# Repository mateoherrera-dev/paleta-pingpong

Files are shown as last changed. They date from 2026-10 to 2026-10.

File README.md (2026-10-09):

# Paleta de ping pong inteligente

Un sensor en el mango de la paleta reconoce cada golpe, mide el angulo de la paleta en el impacto y si el jugador frena antes de la pelota, y muestra un consejo en el celular.

- **Plan de trabajo, modulos y tareas por clase:** [`docs/PLAN.md`](docs/PLAN.md)
- **Formatos de datos entre modulos:** [`docs/CONTRATOS.md`](docs/CONTRATOS.md)

## Estructura

| Carpeta | Que va | Modulo |
| --- | --- | --- |
| `firmware/paleta/` | Codigo de la placa (Arduino IDE) | A |
| `herramientas/` | Python: grabar sesiones, graficarlas, procesar la señal | B y D |
| `app/` | App web que se conecta a la paleta por Bluetooth | C |
| `hardware/` | Capsula en OpenSCAD | E |
| `datos/` | Sesiones grabadas. **No se suben a git**: van al Drive del grupo | Todos |
| `docs/` | Plan, contratos, protocolo de grabacion, criterios | Todos |

## Como arrancar

### Firmware (modulo A)

Configuracion de la placa en el Arduino IDE (la camara no se usa):

- Placa: **ESP32S3 Dev Module**
- Flash Size: **16MB**
- PSRAM: **OPI PSRAM**
- Partition Scheme: **16M Flash (3MB APP/9.9MB FATFS)**
- Si se usa el USB nativo para el monitor serie: USB CDC On Boot → **Enabled**

Conexion del MPU-6500 por SPI (con los nombres que trae impresos el modulo):

| Modulo MPU-6500 | Funcion | ESP32-S3 |
| --- | --- | --- |
| VCC | Alimentacion | 3V3 |
| GND | Masa | GND |
| SCL | SCK (reloj) | GPIO 42 |
| SDA | MOSI | GPIO 41 |
| AD0 | MISO | GPIO 14 |
| NCS | CS | GPIO 21 |
| INT | Dato listo (interrupcion) | GPIO 1 |
| FSYNC, EDA, ECL | - | Sin conectar |

Antes de conectar, revisar en el pinout de su placa que esos GPIO esten libres. Si no, cambiar los `PIN_...` al principio de `paleta.ino`. Al arrancar, el monitor serie tiene que mostrar `# MPU-6500 encontrado (WHO_AM_I = 0x70)`.

Abrir `firmware/paleta/paleta.ino`, cargarlo y abrir el monitor serie a **921600 baudios**.

### Herramientas en Python (modulos B y D)

```bash
cd herramientas
pip install -r requirements.txt
python ejemplo.py
python ver.py ../datos/crudos/ejemplo_sintetico.csv
```

Con la placa conectada:

```bash
python grabar.py --listar
python grabar.py --puerto COM5 --jugador mateo --golpe topspin_derecha
```

### App (modulo C)

Desde la carpeta raiz del proyecto:

```bash
python -m http.server 8000
```

Abrir `http://localhost:8000/app/` en Chrome y tocar **Simulador**. Para usarla en el celular con la placa real hace falta https: publicarla con GitHub Pages.

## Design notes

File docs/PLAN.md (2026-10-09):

# Plan de trabajo

**Condiciones:** somos 3 y trabajamos solo los viernes, de 9 a 16 (a veces hasta las 18). Entre semana no hay trabajo de proyecto, salvo tramites cortos: compras e impresion 3D.

**Calendario:** hoy (viernes 2/10) es la clase 0. El MVP tiene que estar terminado el **viernes 13/11**. Despues viene la fase 2, hasta la entrega final.

| Clase | 1 | 2 | 3 | 4 | 5 | 6 |
| --- | --- | --- | --- | --- | --- | --- |
| Viernes | 9/10 | 16/10 | 23/10 | 30/10 | 6/11 | **13/11 · MVP** |

No hay un viernes de colchon al final. El margen sale de dos lados: el horario de 16 a 18 de cada viernes, y el 13/11, que esta pensado para cerrar y arreglar, no para agregar cosas.

**Objetivo del MVP:** alguien pega un golpe y el celular muestra **que golpe fue, con que angulo pego la paleta y la velocidad de swing estimada ($v = \omega \cdot r$)**, junto con un consejo tecnico.

**Definicion de terminado del MVP:**
- Reconoce 4 golpes (topspin y empuje, de derecha y de reves) con **80 % de aciertos o mas**, medido con gente que no se uso para entrenar.
- Inferencia y metricas locales en el ESP32-S3 (TinyML / Edge Impulse) enviadas por paquete BLE liviano (< 20 bytes) al impactar.
- Muestra en el celular el angulo en el impacto y si el pico de aceleracion angular ocurrio antes de la bola.
- Funciona sin cables a la compu: alimentado por powerbank en el bolsillo via USB-C.

YOLO-pose y el analisis de postura van en la **fase 2**, despues del 13/11.

---

## 1. Equipo y modulos

Los formatos de datos entre modulos estan fijados en [`CONTRATOS.md`](CONTRATOS.md).

| Persona | Modulos | Que hace | Suplente |
| --- | --- | --- | --- |
| **P1 · Hardware** | Firmware base | Sensor MPU-6500 por SPI a 1000 Hz (interrupciones/DMA), deteccion de impactos (trigger), emision de struct BLE (NimBLE) | P2 |
| **P2 · Datos** | Datos, Modelo + 3D | Grabacion (UART), dataset, entrenamiento Edge Impulse, modulo wrapper C++ (`ml_inference.h`), diseño e impresion de capsula (Fusion 360) | P3 |
| **P3 · Tecnica** | App + UI + BLE | Contrato de payload BLE, App web (Web Bluetooth API), calculo cinematico ($v = \omega \cdot L$), angulos (Madgwick), criterios y consejos | P1 |

### Reglas

- **El suplente sabe como funciona el modulo** que cubre, por si el dueño falta un viernes.
- **Los tres graban datos.** La grabacion es una actividad de grupo, no del modulo de datos solo.
- **Integrar todos los viernes.** Cada viernes a la tarde se prueba de punta a punta lo que haya, aunque sea con datos simulados.
- **Los contratos no se cambian solos:** se discute entre los tres y se actualiza `CONTRATOS.md`.
- **Git:** una rama corta por tarea y PR a `main` (que esta protegida), merge cuando compile y ande. Todo pusheado antes de irse cada viernes. Detalle en [`AGENTS.md`](../AGENTS.md).

---

## 2. Como es un viernes

| Horario | Que se hace |
| --- | --- |
| 9:00 – 9:20 | Arranque: que quedo del viernes pasado, que hito tenemos que mostrar hoy |
| 9:20 – 12:30 | **Trabajo por modulos**, cada uno en lo suyo |
| 12:30 – 13:30 | Almuerzo |
| 13:30 – 15:00 | **Bloque de grupo:** grabacion, pruebas con gente o integracion |
| 15:00 – 15:45 | Prueba de punta a punta y control del hito del dia |
| 15:45 – 16:00 | Cierre: commit, tablero, compras y tareas del proximo viernes |
| 16:00 – 18:00 | **Colchon:** solo para lo atrasado, no para cosas nuevas |

---

## 3. Clase 0: hoy

### Organizacion (los tres, primera hora)

- [ ] Confirmar roles: P1, P2 y P3.
- [ ] **Comprar por internet** para recibir antes del 9/10: **2 modulos MPU-6500** (uno de repuesto), cables dupont hembra-hembra, cable USB-C flexible largo (2–3 m) cinta de pintor, cinta bifaz 3M VHB y cinta aisladora. Alternativa de respaldo: 2 discos piezoelectricos chicos por si el trigger por acelerometro mete ruido.
- [ ] Crear el repo en GitHub, subir estructura base y dar permisos al equipo.
- [ ] Crear la carpeta de Drive para los CSV crudos.
- [ ] **Confirmar mesa de ping pong disponible los viernes a la tarde**, red portatil, 2 paletas y minimo 20 pelotas para tiros en rafaga.
- [ ] Averiguar proveedor de impresion 3D y tiempos de entrega (impresion entre Clase 3 y 4).
- [ ] Contactar al jugador de referencia para coordinar su asistencia el viernes 30/10 (Clase 4).

### Codigo y Banco (sin sensor fisico aun)

| Quien | Tarea | Listo cuando… |
| --- | --- | --- |
| **P2** | Escribir modulo wrapper C++ (`ml_inference.h/cpp`) integrando el modelo Edge Impulse sintetico (`firmware/modelo_dummy_sintetico.zip`) | Modulo encapsulado listo con funcion `predecir_golpe()` |
| **P2** | Script receptor en Python por puerto serie (lectura a 921600 baudios) y visualizador `ver.py` | Recibe paquetes simulados a 1000 Hz sin dropping de buffers |
| **P2** | Escribir protocolo de captura (`docs/PROTOCOLO.md`): orden de tiros, estructura y metadatos de CSV | Protocolo cerrado |
| **P3** | App web base (Web Bluetooth API) desplegada en GitHub Pages | Conecta y parsea el string de prueba del contrato |
| **P3** | Definir rangos biomecanicos preliminares (angulos de impacto y velocidad tangencial) | Tabla base en `docs/` |

---

## 4. Fase 1: MVP, viernes por viernes

### Clase 1 · Viernes 9/10 · Señal real y adquisicion a 1000 Hz (Alimentacion: Cable USB-C a PC)
**Materiales a llevar:** Placa ESP32-S3, MPU-6500, cable USB-C largo (2-3 m), paleta, cinta de pintor, cinta bifaz 3M VHB, cinta aisladora / edge tape, pelotas de ping pong.

| P1 | P2 | P3 |
| --- | --- | --- |
| Configurar IDE para ESP32-S3 y linkear `ml_inference.h` (prueba dummy). Mapear pines, conectar MPU-6500 por SPI $\ge 1\text{ MHz}$, y configurar muestreo a 1000 Hz por interrupcion | Modelar capsula de la placa en Fusion 360 midiendo componentes. Validar aislacion del impacto real vs swings al aire | Algoritmo de orientacion (Madgwick/Mahony) en Python procesando las rafagas. Definir contrato de payload BLE (struct C) |

**Tarde:** 
1. **Montaje provisorio (13:30):** Pegar la plaqueta pelada del MPU-6500 a la madera usando cinta de pintor + VHB, y encintar los cables al canto (protocolo 7.3) para evitar ruido mecanico. Al terminar el dia se despega todo.
2. **Grabacion:** 30-40 min de capturas con cable USB largo (swings al aire vs. golpes reales contra pelota).
**Hito:** Señal limpia a 1000 Hz en PC y trigger de impacto validado sin falsos positivos.
*⚠️ Salvavidas (Plan B):* Si a las 11:30 AM P1 no logra estabilizar las interrupciones de hardware, abortar y usar un bucle de *polling* bruto (`delayMicroseconds`) para garantizar la grabacion de la tarde.

### Clase 2 · Viernes 16/10 · Grabacion masiva del Dataset (Alimentacion: Cable USB-C a PC)
**Materiales a llevar:** Setup fisico de Clase 1, MPU-6500 de repuesto, cinta plana de 7 vias, cinta Kapton, termocontraible fino, minimo 20 pelotas de ping pong y red portatil.

| P1 | P2 | P3 |
| --- | --- | --- |
| Implementar buffer circular en ESP32-S3 (congelar ventana de 200 ms alrededor del impacto) y testear BLE en dummy | Script de segmentacion automatica de impactos y formateo directo para Edge Impulse | Pruebas de estimacion de velocidad tangencial ($v = \omega_{\text{swing}} \cdot L$) y visualizacion en tiempo real |

**Montaje definitivo del sensor (Clase 2):** la capsula impresa no llega para esta clase, pero el sensor ya queda pegado en su lugar final. La capsula es solo una tapa que no toca el sensor y se agrega en la Clase 4 sin moverlo, asi que el dataset de la tarde se graba con el montaje que va a tener la paleta terminada.

1. **Preparacion del sensor de repuesto (Hardware limpio)**
   - No soldar la tira de pines (headers) recta: Dejar los orificios del PCB libres de conectores macho.
   - Soldar cable plano (ribbon cable) directamente a los pads:
     - Cortar un tramo de cinta plana de 7 vias (longitud aprox. 12 a 15 cm hasta la base del mango).
     - Pelar y estañar las puntas apenas 1 mm.
     - Soldar cada hilo directamente en los orificios de la interfaz SPI: VCC, GND, SCL/SCLK, SDA/SDI, AD0/SDO, NCS e INT.
     - Doblar los cables en un angulo plano de 90° inmediatamente al salir del estaño hacia el mango.
   - Aislacion y perfil bajo: Colocar cinta Kapton sobre las soldaduras para evitar contactos. Espesor total: < 3 mm.
   - Recalibrar el offset del acelerometro con `herramientas/calibrar.py` (es otro modulo) y actualizar `OFFSET_A*_G` en `paleta.ino`.

2. **Fijacion en la madera**
   - Marcar en el cuello el contorno de la capsula (medidas en la seccion 7.1), para que el sensor quede donde despues lo va a tapar.
   - Pegar el MPU con cinta de pintor + VHB (seccion 7.3), rigido contra la madera y **paralelo a la cara de la paleta**, no apoyado sobre el chaflan. Si queda inclinado, los ejes dejan de coincidir con `CONTRATOS.md` y el angulo de la cara sale corrido.
   - Llevar la cinta plana por el canto del mango y cubrirla con edge tape (seccion 7.3).

3. **Conexion hacia el mango**
   - En el extremo del cable plano en el mango, soldar terminales dupont hembra (sirven los de cables dupont cortados, con termocontraible) para conectar a la ESP32-S3, respetando los pines SPI ya probados: SCL→42, SDA→41, AD0→14, NCS→21, INT→1.
   - Comprobar continuidad con multimetro antes de encender para descartar cortos entre lineas SPI adyacentes.

4. **Verificar ejes y angulo (antes de grabar)**
   - Paleta acostada con la goma roja arriba y el mango fuera del borde de la mesa (asi la cara queda horizontal): tiene que dar `az` ≈ +1 g y `ax`, `ay` ≈ 0 g.
     - Si `az` da −1 g, el modulo quedo mirando para el lado negro: invertir los ejes en `alinearEjes()`.
     - Si `ax` o `ay` se alejan de 0 (0.05 g ≈ 3°), el sensor quedo inclinado: volver a pegarlo derecho o corregir esa inclinacion en `alinearEjes()`.
   - Paleta vertical con el mango abajo: tiene que dar `ax` ≈ +1 g.

**Tarde: Grabacion masiva** con el sensor ya en su lugar definitivo. Los tres: 50 golpes por tipo (Topspin Der/Rev, Empuje Der/Rev) $\approx$ 600 tiros.
**Hito:** Sensor de repuesto montado en su lugar definitivo y Dataset v1 subido a Drive y segmentado para entrenamiento.
*⚠️ Criterio de Trigger (Plan B):* Evaluar si el acelerometro detecta limpiamente el impacto sin falsos positivos. Si anda bien, se descarta el piezoelectrico. Si mete ruido, el piezoelectrico entra al diseño 3D y hardware de inmediato.

### Clase 3 · Viernes 23/10 · Despliegue TinyML y Pase a Inalambrico (Alimentacion: Powerbank en bolsillo)
**Materiales a llevar:** Paleta ensamblada provisional, Powerbank de bolsillo, cable USB-C estandar (bolsillo a paleta), celular de prueba para P3.

| P1 | P2 | P3 |
| --- | --- | --- |
| Pasar a alimentacion por Powerbank (verificar que no corte) y emitir struct de prediccion por NimBLE al detectar impacto | Entrenar modelo en Edge Impulse, optimizar cuantizacion INT8, exportar C++ y actualizar `ml_inference.h` | Conectar app web con el BLE real: parsear struct (payload C cerrado) y actualizar UI al impacto |

**Tarde:** Capturar a 3–5 compañeros de la facultad con la paleta inalambrica para validar precision fuera del dataset de entrenamiento.
**Hito:** Precision medida en hardware real.
- $\ge 80\%$: se avanza a integracion final.
- $60\% - 80\%$: reentrenamiento con golpes ambiguos.
- $< 60\%$: reducir alcance a 3 golpes.

**Durante la semana:** P2 envia la capsula y el capuchon a imprimir en 3D (medidas y parametros de impresion en la seccion 7.1).

### Clase 4 · Viernes 30/10 · Integracion Total y Ensamble Definitivo
**Materiales a llevar:** Piezas impresas en 3D (Capsula y Capuchon traidas por P2), adhesivo removible / masilla, herramientas menores para ensamble final.

| P1 | P2 | P3 |
| --- | --- | --- |
| Calce en seco de la capsula sobre el sensor ya pegado (la cuña apoya plana en el chaflan y la cinta plana pasa holgada), pegar su perimetro con adhesivo removible / masilla sin tocar el sensor, montar la ESP32-S3 en el capuchon y verificar alivio de tension USB | Cargar modelo exportado de Edge Impulse en firmware y verificar estabilidad SPI a 1000 Hz | Enlazar Web App por BLE (struct 14 bytes) y validar refresco de UI con golpes en vivo |

**Tarde (los tres):** Prueba de humo de punta a punta con la paleta ensamblada. 20 golpes de cada tipo entre los integrantes del grupo para chequear autonomia y robustez mecanica.  
**Hito:** Paleta armada en su carcasa definitiva, transmitiendo metricas al celular sin cables a la PC.

---

### Clase 5 · Viernes 6/11 · Validacion Ciega y Ajuste Heuristico
**Materiales a llevar:** Hardware 100% ensamblado y funcional, red y pelotas para las pruebas ciegas.

| P1 | P2 | P3 |
| --- | --- | --- |
| Calibrar umbrales de trigger de impacto para eliminar falsos positivos por roces | Ajustar umbral de confianza en inferencia (descartar tiros ambiguos a clase 4) | Pulir reglas heuristicas de consejos segun cinematica teorica (angulos y pico de giro) |

**Tarde:** Sesion de pruebas de usabilidad y acierto ciego con 3 a 5 compañeros ajenos a la carrera para medir la generalizacion del modelo.  
**Congelamiento de codigo al finalizar la jornada.**  
**Hito:** Precision $\ge 80\%$ validada en personas externas al entrenamiento y codigo 100% congelado.

### Clase 6 · Viernes 13/11 · MVP Terminado
**Materiales a llevar:** MVP completo, Powerbank cargado al 100%, camara o celular extra con buen almacenamiento y tripode para filmar la demo.

- **Mañana:** Calibraciones menores y pruebas de estres de bateria/enlace BLE.
- **Tarde:** Medicion de metricas finales (latencia, acierto, bateria), ensayo general y **filmacion de la demo de respaldo**.

**Hito: MVP 100 % completado.**

---

### 4.7 Calculo de Angulo y Filtro de Orientacion (Parte del MVP)

**¿Por que esta en el MVP?**
En `CONTRATOS.md`, el struct binario de 14 bytes (`BlePayload`) que P1 le manda por Bluetooth a P3 incluye explicitamente el campo:
```cpp
int16_t ang_deg; // 2 bytes: Angulo de la cara (- cerrada, + abierta)
```
Si no calculan la orientacion de la paleta, ese campo viaja en 0 o con basura, y la Web App de P3 no puede mostrar si el jugador impacto con la paleta abierta o cerrada.

#### 1. Donde SI se necesita un filtro (Calculo del angulo de la cara)
Para completar el campo `ang_deg` y saber si la paleta entro abierta o cerrada, necesitas conocer la orientacion espacial de la madera respecto a la gravedad:
- **El problema fisico:** En medio de un swing de tenis de mesa no podes calcular el angulo simplemente con $\arctan(a_z / a_x)$, porque las aceleraciones centripeta y tangencial superan por mucho a la gravedad ($1\text{ g}$) y falsean el vector vertical.
- **La solucion:** Un algoritmo de orientacion espacial (*attitude estimation*) que integre el giroscopio y use el acelerometro para corregir la deriva (*drift*) lentamente.

#### 2. Como resolverlo sin volverse locos en el MVP
No tienen que programar las ecuaciones de Madgwick desde cero en C++. Hay dos caminos directos:

**Opcion A: La via estandar (Libreria probada en Arduino/ESP-IDF)**
Usar la libreria `MadgwickAHRS` (disponible en el gestor de librerias de Arduino). Son apenas dos llamadas:
```cpp
Madgwick filter;
filter.begin(100); // Se actualiza a 100 Hz, no a 1000 Hz

// En el loop:
filter.updateIMU(gx, gy, gz, ax, ay, az);
float pitch = filter.getPitch(); // o el angulo sobre el eje normal
```

**Opcion B: El "atajo" heuristico de MVP (Filtro complementario de 3 lineas)**
Si Madgwick les da problemas de ajuste de ganancia ($\beta$) durante la Clase 1 o 2:
- Antes del swing (cuando la paleta esta casi quieta), calculan el angulo base con el acelerometro: $\theta_{\text{acc}} = \arctan2(a_z, a_x) \cdot \frac{180}{\pi}$.
- Durante los ~150 ms del golpe rapido, integran puramente el giroscopio: $\Delta\theta = \int g_y \, dt$.
- Angulo al impacto = $\theta_{\text{base}} + \Delta\theta$.

#### 3. Implementacion practica: No calcular a 1000 Hz
No es necesario correr el filtro Madgwick a 1000 Hz durante toda la sesion:
- **Fase de preparacion ($t < -150\text{ ms}$):** El jugador prepara el tiro. Ahi el movimiento es suave. Correr Madgwick o un filtro complementario liviano a 100 o 200 Hz mantiene orientado el cuaternion del sistema.
- **Fase de swing rapido / impacto:** Congelas la correccion del acelerometro (pones $\beta = 0$ para que el choque de la pelota no incline la estimacion) e integras puramente la rotacion del giroscopio durante los 50 ms previos al impacto.

**Conclusion de Fase 1 (MVP actual):** Inferencia de los 4 golpes en el ESP32 + calculo del angulo `ang_deg` e impacto por IMU + envio por BLE al celular.

## 5. Fase 2: Video de Entrega y Tracking de Postura (Post 13/11)

- **Grabacion final:** Una sola toma lateral a 3 metros (altura de cadera), 60 fps, con iluminacion uniforme.
- **Superposicion sincronica:** Procesamiento en Python con YOLOv8-pose / YOLO11-pose para extraer esqueleto (17 keypoints), sincronizado con el impacto del sensor via audio del golpe.
- **Comparacion biomecanica:** Contrastar flexion de rodillas y codo del usuario vs. clips de entrenadores de referencia.

---

### 5.1 Modo Tutorial: Entrenador Biomecanico Interactivo (Feature Practica)

Para que el proyecto tenga rigor tecnico y no hagan promesas falsas ante los profesores, hay que tener claro el alcance del sensor.

#### 1. El limite fisico: que puede y que NO puede decir la app
**Lo que el sensor SI sabe (en la paleta):**
- Angulo de la cara en el momento exacto del impacto (`ang_deg`).
- Velocidad tangencial estimada del golpe (`vel_kmh`).
- Cuando acelero la muñeca respecto al impacto (`pico_ms`).
- Si el movimiento fue de cepillado (*brushing*) o de empuje plano/bloqueo (segun los ratios $\omega / a_z$).

**Lo que el sensor NO sabe (y no deben inventar):**
- Posicion de los pies, cadera o codo (eso requeriria camara o sensores en el cuerpo).

**Regla de oro de los feedbacks:**
- La app **nunca** debe decir: *"Abri mas el codo"* o *"Flexiona las rodillas"*.
- La app **si** debe decir: *"Entraste con la cara 15° demasiado abierta"* o *"Aceleraste despues del impacto; el latigo de muñeca tiene que ser antes"*.

#### 2. Como se estructura el "Modo Tutorial"
En la web app de P3, en vez de limitarse a mostrar una tabla de metricas crudas, se armara una pestaña "Academia / Tutoriales" con objetivos por niveles.

**Modulo: "Aprender Topspin de Derecha (Comba)"**
El usuario entra a una pantalla con 3 pasos guiados:

- **Paso 1: Angulo de ataque (Cerrar la cara)**
  - **Objetivo:** Lograr 5 golpes seguidos con la cara cerrada entre $-15^\circ$ y $-35^\circ$.
  - **Feedback visual:** La app muestra un grafico o indicador de aguja.
  - **Regla:** Si `ang_deg > -5°`, disparar audio/texto: *"Paleta muy vertical. Vas a tirar la pelota afuera; cerra la muñeca hacia la mesa"*.

- **Paso 2: El 'Brushing' (Velocidad de roce vs. Choque)**
  - **Objetivo:** Superar los $15\text{ km/h}$ o cierto umbral de aceleracion angular ($\omega_y > 800^\circ/\text{s}$) asegurando que el tipo de golpe sea clasificado como Topspin por Edge Impulse.
  - **Regla:** Si el modelo clasifica como Empuje pero el jugador intento hacer topspin, disparar audio/texto: *"Estas empujando la pelota plana. Hace un arco ascendente de abajo hacia arriba"*.

- **Paso 3: Timing del latigo (El pico de giro)**
  - **Objetivo:** Con la metrica `pico_ms` del struct: si el pico maximo de rotacion angular ocurrio despues de tocar la pelota (`pico_ms > 0`), el golpe fue trabado.
  - **Feedback:** *"Llegaste tarde con la aceleracion. El pico de velocidad tiene que alcanzarse justo antes del impacto"*.

#### 3. Esfuerzo de desarrollo vs. Impacto real
- **Complejidad de codigo (P3): Baja / Media.**
  Son condicionales puros (`if`/`else`) sobre el `BlePayload` que ya reciben en la web app via Web Bluetooth. Solo implica armar una interfaz con tarjetas de desafios (*"Desafio: 5 topspins con cara cerrada"*), un contador de progreso y un sintetizador de voz del navegador (`window.speechSynthesis`) para que el celular hable en tiempo real mientras el jugador tiene la paleta en la mano.
- **Impacto en la evaluacion: Altisimo.**
  Pasan de presentar *"un hardware con acelerometro que tira numeritos en pantalla"* a presentar *"un entrenador biomecanico interactivo de tenis de mesa"*.

## 6. Matriz de Riesgos y Planes de Contingencia

| Riesgo | Plan B |
| --- | --- |
| P1 trabado con interrupciones del ESP32 a 1000 Hz | Pasar temporalmente a *polling* (`delayMicroseconds(900)`) en el `loop()` para no bloquear la grabacion de P2 |
| MPU-6500 saturado o con ruido en SPI | Bajar frecuencia SPI a 1 MHz; si el bus I2C ya viene armado en la breakout, forzar Fast Mode (400 kHz) |
| Falsos positivos en trigger de impacto por aceleracion | Soldar disco piezoelectrico en pin ADC como comparador analogico puro de vibracion |
| Powerbank se apaga por bajo consumo en reposo | Colocar carga resistiva en paralelo o forzar loop de calculo continuo sin entrar en deep sleep |
| Modelo pesado o latencia alta en ESP32-S3 | Cuantizar a `int8` en Edge Impulse o clasificar por arbol de decision directo sobre picos de $\omega$ |
| Falla en enlace BLE durante la demo | Conexion cableada por puerto serie mostrando los mismos datos en consola/web |

---

## 7. Especificaciones Mecanicas y de Montaje (P2)

### 7.1 Que modelar en Fusion 360
Diseña dos piezas impresas en PETG o PLA (paredes de 1.6 mm a 2.0 mm):

**Pieza 1 — Capsula del Sensor (MPU-6500):**
- Medidas tomadas sobre la paleta el 9/10: 30 mm de ancho, 20.5 mm de largo, alto en rampa de 6 a 9.8 mm, peso $< 5\text{ g}$.
- Base en cuña compensada que apoya plana sobre el chaflan de la madera del cuello.
- Domo que tapa la plaqueta del MPU-6500 sin tocarla (el sensor va pegado a la madera, no a la capsula).
- Ranura pasacables de 12 × 2.5 mm en el canto inferior para la **cinta plana de 7 vias** (VCC, GND, SCL, SDA, AD0, NCS, INT), con traba interna de alivio de tension (*strain relief*).
- Las 7 vias quedan ocupadas por el sensor: si entra el piezoelectrico (Plan B), probablemente vaya en la otra cara de la paleta, con su propio cable.
- Impresion: capa de 0.2 mm, 3 o 4 perimetros (paredes de 1.6 mm solidas), boca abajo apoyada sobre el techo plano, sin soportes.

**Pieza 2 — Capuchon Prolongador del Mango (ESP32-S3):**
- Diseño tipo "vaina" o capuchon que prolonga el mango 3.5 a 4 cm hacia abajo en vertical, sin aletas laterales que sobresalgan del perfil de la mano.
- Zona superior (encastre): Cavidad que abraza los ultimos 15 mm del mango de la paleta copiando su forma eliptica/concava, con apriete por friccion o ranura para una vuelta de cinta exterior.
- Zona inferior (electronica): Aloja la placa ESP32-S3 orientada de forma vertical (en la misma direccion del eje del mango).
- Abertura en la base inferior centrada para conectar el cable USB-C de alimentacion.
- Entrada superior para recibir los cables del bus SPI que bajan por el canto.
- Aristas redondeadas con filetes (*fillets*) de radio amplio para que el talon de la palma descanse sin molestias.

### 7.2 Donde ubicar cada componente
- **MPU-6500:** En el cuello de la paleta (el triangulo de madera descubierta entre el mango y la goma), en la cara donde no apoye el dedo indice.
  *Por que ahi:* Esta pegado a la zona de juego (a 2–3 cm del contacto), capturando la vibracion pura del impacto ($>150\text{ Hz}$) y el angulo exacto de la madera sin la amortiguacion de los tejidos de la mano.
- **ESP32-S3:** En el extremo inferior del mango (el pomo), alineado longitudinalmente dentro del capuchon.
  *Por que ahi:* Al estar ubicado en el eje de rotacion de la muñeca, los 10–12 gramos extra de la placa y la carcasa tienen un momento de inercia practicamente despreciable; la punta de la paleta se siente igual de agil.
- **Alimentacion (Powerbank):** En el bolsillo del pantalon.

### 7.3 Como montarlo y cablearlo
- **Fijacion del sensor a la madera:**
  1. Limpia la zona del cuello con alcohol.
  2. Pega primero un parche de cinta de enmascarar (cinta de papel de pintor) bien estirada sobre la madera (cinta de sacrificio).
  3. Encima de la cinta de papel, coloca cinta bifaz (3M VHB).
  4. Apoya la cara metalica del **disco piezoelectrico** y la base del **MPU-6500** presionando firmemente directo contra el VHB. *(El piezoelectrico NUNCA va encastrado en las paredes de plastico porque el plastico actuaria como filtro pasabajos disipando la onda de la madera).* 
  5. La capsula 3D se coloca por arriba actuando simplemente como un **domo protector** que los cubre, sin apretarlos ni dejarlos sueltos.
- **Puente del bus SPI (Capsula 1 $\rightarrow$ Capsula 2):**
  - **Ordenar los cables en cinta plana:** No armes una trenza ni un manojo cilindrico grueso. Peina los 7 hilos para que queden planos, uno al lado del otro en paralelo, formando una franja plana de menos de 1 mm de espesor.
  - **Primera fijacion (Inmovilizacion puntual):** Apoya la franja de cables recorriendo el canto lateral estrecho del mango (la madera del canto entre las dos cachas donde no cierran los dedos). Pega dos tiritas finas de cinta de papel o cinta scotch transparente bien tensadas (una cerca del cuello y otra cerca de la base) para que los cables no se muevan de su carril mientras trabajas.
  - **Fijacion mecanica definitiva y proteccion:** Cubri todo el canto lateral del mango de arriba a abajo usando una vuelta de cinta de borde para paleta de ping pong (*edge tape*) o cinta aisladora de PVC de buena calidad. Aplicala estirandola con fuerza para que abrace la madera y copie el relieve. La cinta sella los cables contra el sudor de la mano, evita roces y deja el mango completamente liso al tacto.
- **Alimentacion hacia el cuerpo:**
  - Enchufa un cable USB-C liviano y flexible a la base del capuchon.
  - Pasalo por dentro de la manga de la remera hacia el powerbank en el bolsillo, dejando una comba floja a la altura del codo para bracear libremente sin tirones.

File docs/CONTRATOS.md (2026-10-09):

# Contratos entre modulos

Estos formatos son lo que permite que cada uno trabaje en su parte sin esperar a los demas.
**Si alguien necesita cambiar algo de aca, lo charla con todo el grupo y lo anota en este archivo antes de tocar el codigo.**

## 1. Ejes del sensor

Todos los datos usan los mismos ejes, medidos sobre la paleta (no sobre el modulo):

```
            cara roja (frente)
                 ▲ Z
                 │
          ┌──────┴──────┐
          │             │
          │   paleta    │ ──► X  (hacia la punta de la paleta,
          │             │        a lo largo del mango)
          └──────┬──────┘
                 │ mango
                 ●  sensor
       Y = Z × X  (hacia el canto, regla de la mano derecha)
```

- **X**: a lo largo del mango, apuntando hacia la paleta.
- **Z**: perpendicular a la cara, saliendo por la goma **roja**.
- **Y**: hacia el canto, completando un sistema de mano derecha.

Si el modulo no se puede montar con esos ejes, se reordenan en el firmware (`alinearEjes()` en `firmware/paleta/paleta.ino`). Las herramientas de Python y la app asumen siempre estos ejes.

## 2. Muestras crudas (placa → compu, por cable USB)

Una linea de texto por muestra, **1000 muestras por segundo**:

```
t_us,ax_g,ay_g,az_g,gx_dps,gy_dps,gz_dps,impacto
```

| Campo | Unidad | Detalle |
| --- | --- | --- |
| `t_us` | microsegundos | Tiempo desde que arranco la placa |
| `ax_g`, `ay_g`, `az_g` | g | Aceleracion, rango ±16 g |
| `gx_dps`, `gy_dps`, `gz_dps` | °/s | Velocidad de giro, rango ±2000 °/s |
| `impacto` | 0 o 1 | 1 si la placa detecto un impacto en esa muestra |

Las lineas que empiezan con `#` son mensajes y se ignoran.

## 3. Archivos de sesion

- Nombre: `AAAA-MM-DD_HHMMSS_jugador_golpe.csv` (lo arma `herramientas/grabar.py`).
- Golpes validos: `topspin_derecha`, `topspin_reves`, `empuje_derecha`, `empuje_reves`, o `libre` para juego libre.
- Se guardan en `datos/crudos/`. **No se suben a git** (pesan mucho): se comparten en la carpeta de Drive del grupo.

## 4. Interfaz de Inferencia C++ (P1 ↔ P2)

Para aislar el codigo de adquisicion de hardware (P1) del modelo de Machine Learning de Edge Impulse (P2), la comunicacion interna del ESP32 se rige estrictamente por el wrapper `firmware/paleta/ml_inference.h`.

- **Entrada (Buffer):** P1 invoca la inferencia pasando un array de **1176 floats** estaticos. Este valor esta fijado por la constante `ML_BUFFER_LONGITUD_ESPERADA`, representando 196 ms de captura (196 muestras $\times$ 6 ejes IMU a 1000 Hz).
- **Salida (Struct):** P2 procesa la señal y devuelve un `PrediccionGolpe` purgado de tipos de TensorFlow:
  ```c
  typedef struct {
      const char* etiqueta;      // ej. "topspin_derecha"
      float probabilidad;        // 0.0 a 1.0
      float tiempo_inferencia_ms;
  } PrediccionGolpe;
  ```

## 5. Evento de golpe BLE (P1 ↔ P3)

Para evitar el bloqueo de interrupciones en el ESP32 causado por el parseo y concatenacion de strings, el Bluetooth Low Energy transmite un **Struct de C empaquetado (Packed Struct)** binario. Ocupa solo 14 bytes y entra sobradamente en un paquete BLE estandar (MTU 20).

- **Servicio Custom:** `6e400001-b5a3-f393-e0a9-e50e24dcca9e`.
- **Caracteristica de Notificacion (Notify):** `6e400003-b5a3-f393-e0a9-e50e24dcca9e`.

### Estructura de Datos (C++ ESP32)
```c
#pragma pack(push, 1)
struct BlePayload {
    uint32_t timestamp;     // 4 bytes: ms desde el arranque del ESP32
    uint16_t numero_golpe;  // 2 bytes: contador de impactos en la sesion
    uint8_t  tipo_golpe;    // 1 byte: 0=TD, 1=TR, 2=ED, 3=ER, 4=Desconocido
    uint8_t  confianza;     // 1 byte: Probabilidad de Edge Impulse (0 a 100)
    int16_t  vel_kmh;       // 2 bytes: Velocidad tangencial estimada
    int16_t  ang_deg;       // 2 bytes: Angulo de la cara (- cerrada, + abierta; ver abajo)
    int16_t  pico_ms;       // 2 bytes: Tiempo del pico giro vs impacto (- es antes)
}; // Total: 14 bytes
#pragma pack(pop)
```

### Signo del angulo (`ang_deg`)

Misma convencion que [`GOLPES.md`](GOLPES.md), donde estan los rangos de cada golpe:

| Valor | Cara de la paleta | Golpe tipico |
| --- | --- | --- |
| **0°** | Vertical, perpendicular a la mesa | — |
| **Negativo** | **Cerrada**: mira hacia la mesa | Topspin (ideal entre −40° y −15°) |
| **Positivo** | **Abierta**: mira hacia el techo | Empuje (ideal entre +25° y +50°) |

### Recepcion (Web App P3)
P3 se suscribe a la caracteristica usando la **Web Bluetooth API**. Al recibir el buffer binario, lo decodifica usando un `DataView` estandar de JavaScript en formato **Little-Endian**:
```javascript
let timestamp = dataView.getUint32(0, true);
let tipo_golpe = dataView.getUint8(6);
let vel_kmh = dataView.getInt16(8, true);
```

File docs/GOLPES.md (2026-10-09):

# Criterios Biomecanicos y Reglas de Retroalimentacion

Este documento compila los fundamentos tecnicos de los cuatro golpes base analizados en las lecciones de *PingSkills*, su traduccion a signaturas inerciales (IMU MPU-6500) y las reglas deterministicas para la generacion automatica de feedback en la aplicacion.

---

## 1. Arquitectura del Sistema de Retroalimentacion

El sistema opera mediante una separacion estricta entre la **clasificacion de intencion motora** y la **evaluacion de calidad tecnica**:

1. **Clasificacion (Edge Impulse / TinyML):** Identifica el gesto ejecutado (`TD`, `TR`, `ED` o `ER`).
2. **Extraccion Cinematica:** Calcula de forma deterministica:
   * $\theta_{\text{impacto}}$: Inclinacion angular de la cara de la paleta en el choque (grados respecto a la vertical, donde $0^\circ$ es perpendicular a la mesa, valores negativos miran hacia abajo y positivos hacia el techo).
   * $\omega_{\max}$: Velocidad angular pico del swing.
   * $\Delta t_{\text{pico}} = t_{\omega_{\max}} - t_{\text{impacto}}$: Desfasaje temporal entre el punto de maxima aceleracion angular y el contacto con la pelota.
   * $\text{Giro}_{\text{lateral}}$: Componente de rotacion fuera del plano principal de avance.
3. **Motor de Reglas Condicional:** Aplica umbrales heuristicos especificos para la clase detectada y selecciona una unica recomendacion prioritaria.

---

## 2. Analisis por Golpe

### A. Topspin de Derecha contra Corte (Forehand Topspin Against Backspin — TD)
https://www.youtube.com/watch?v=_Bi3vOTH_do

#### Tecnica segun PingSkills
* **Posicion inicial y trayectoria:** La paleta arranca baja, a la altura de la rodilla (*knee high*), con la cara levemente abierta para poder entrar bajo el efecto cortado rival.
* **Contacto y terminacion:** El contacto exige un raspado ascendente (*brushing action*). La trayectoria debe ser marcadamente vertical, finalizando por encima del nivel de los ojos (*above eye level*) con una flexion angular aproximada de 90° en el codo.
* **Errores frecuentes:** Iniciar el swing a la altura de la mesa (demasiado alto), avanzar con trayectoria puramente horizontal o entrar con la cara excesivamente cerrada, lo que impide contrarrestar el backspin entrante y envia la bola a la red.

#### Signatura Inercial (IMU)
* Vector de aceleracion vertical marcadamente positivo en la ventana previa al impacto (transicion desde altura de rodilla hacia arriba).
* Rotacion horaria de antebrazo/muñeca en el eje longitudinal/transversal.
* Pico de velocidad angular $\omega_{\max}$ alineado con el instante del choque.

#### Reglas Deterministicas de Evaluacion
* **Rango ideal de angulo ($\theta_{\text{impacto}}$):** $[-40^\circ, -20^\circ]$
* **Tolerancia de timing ($\Delta t_{\text{pico}}$):** $\ge -25\text{ ms}$
* **Aceleracion vertical minima previa:** $a_{\text{vertical}} \ge a_{\text{min\_lift}}$

```text
SI a_vertical < a_min_lift:
    RETORNAR "Inicia el swing mas abajo (altura de rodilla) y termina sobre los ojos para levantar la bola."
SINO SI θ_impacto > -5°:
    RETORNAR "Cara excesivamente abierta; cerra levemente la paleta para que no flote al fondo."
SINO SI θ_impacto < -45°:
    RETORNAR "Cara muy cerrada; estas tapando la pelota y el corte rival la tirara a la red."
SINO SI Δt_pico < -35 ms:
    RETORNAR "Estas frenando la mano antes del contacto; acelera a traves de la pelota."
SINO:
    RETORNAR "Topspin de derecha optimo: trayectoria ascendente y aceleracion fluida."
```

---

### B. Topspin de Reves contra Corte (Backhand Topspin — TR)
https://www.youtube.com/watch?v=LmQNDC-1Ew0

#### Tecnica segun PingSkills
* **Posicion inicial:** La paleta debe descender al menos hasta la altura de las rodillas para situarse por debajo de la trayectoria de la bola y permitir una trayectoria de elevacion neta.
* **Extension y aceleracion:** El contacto exige un raspado fino. El swing no debe interrumpirse al momento del choque: el brazo y la muñeca deben proyectarse hacia arriba hasta superar la altura de la cabeza, permitiendo que la paleta sobrepase la linea del codo (*swing past your elbow*).
* **Errores frecuentes:** Desacelerar la mano por miedo a fallar, o no descender lo suficiente en la preparacion, provocando que la rotacion contraria de la pelota entrante (backspin) la arrastre directo a la red.

#### Signatura Inercial (IMU)
* Inversion de polaridad en el giroscopio respecto al topspin de derecha (movimiento de supinacion y extension de reves).
* Elevacion marcada del vector de aceleracion lineal previo al choque.
* Curva de velocidad angular pronunciada con pico sostenido durante el *follow-through*.

#### Reglas Deterministicas de Evaluacion
* **Rango ideal de angulo ($\theta_{\text{impacto}}$):** $[-35^\circ, -15^\circ]$
* **Tolerancia de timing ($\Delta t_{\text{pico}}$):** $\ge -25\text{ ms}$
* **Intensidad angular ($\omega_{\max}$):** Debe superar el umbral minimo de aceleracion del swing ($\omega_{\text{min\_tr}}$).

```{text}
SI θ_impacto > 0°:
RETORNAR "Entraste con la cara abierta; inclina la paleta hacia la mesa para superar la red."
SINO SI Δt_pico < -35 ms O ω_max < ω_min_tr:
RETORNAR "No cortes el golpe; deja que la paleta pase la linea del codo con aceleracion continua."
SINO SI θ_impacto < -45°:
RETORNAR "Angulo excesivamente cerrado; abri ligeramente la cara para dar altura al tiro."
SINO:
RETORNAR "Topspin de reves consistente: buena extension y raspado."
```

---

### C. Empuje de Derecha (Forehand Push — ED)
https://www.youtube.com/watch?v=x6wQmAoTA_o&t=1s 

#### Tecnica segun PingSkills
* **Posicion y angulo de la cara:** La paleta se situa lateralmente con la cara inclinada hacia atras (*tilted back*, orientada hacia el techo) para entrar por debajo de la pelota y generar backspin defensivo.
* **Mecanica del brazo:** El agarre y los dedos deben mantenerse relajados. La paleta avanza hacia la mesa y hacia la red en linea recta. Si el jugador aprieta la empuñadura en exceso, la muñeca se bloquea y el brazo cruza el cuerpo en diagonal, perdiendo precision direccional.
* **Errores frecuentes:** Entrar con la cara vertical o cerrar el golpe antes de tiempo, impidiendo contrarrestar el efecto de la pelota entrante.

#### Signatura Inercial (IMU)
* Componente estatico de aceleracion previa con la normal de la pala orientada hacia arriba ($+a_z$).
* Aceleracion traslacional suave hacia el frente; valores moderados en giroscopios (golpe de control, no de potencia).
* Valores reducidos de rotacion en el eje lateral de la pala.

#### Reglas Deterministicas de Evaluacion
* **Rango ideal de angulo ($\theta_{\text{impacto}}$):** $[+30^\circ, +50^\circ]$
* **Desviacion angular transversal ($\text{Giro}_{\text{lateral}}$):** $\le \text{Umbral}_{\text{cruzado}}$

```{text}
SI θ_impacto < +20°:
RETORNAR "Abri la cara de la paleta hacia arriba para entrar bien por debajo de la pelota."
SINO SI Giro_lateral > Umbral_cruzado:
RETORNAR "Relaja la muñeca: empuja recto hacia la red sin cruzar el brazo delante del pecho."
SINO SI θ_impacto > +60°:
RETORNAR "Paleta demasiado abierta; la pelota se elevara demasiado facilitando el remate rival."
SINO:
RETORNAR "Empuje de derecha correcto: angulo de corte limpio y trayectoria controlada."
```

---

### D. Empuje de Reves (Backhand Push — ER)
https://www.youtube.com/watch?v=hqiiVW7BG1A 

#### Tecnica segun PingSkills
* **Inicio y terminacion:** El movimiento se origina frente al cuerpo con la cara de la paleta abierta hacia atras. El contacto raspa la base inferior de la pelota y la terminacion avanza hacia adelante en direccion a la red.
* **Adaptacion al spin:** Ante pelotas rivales con fuerte corte, se requiere inclinar la cara mas hacia atras para neutralizar el backspin entrante y evitar que la pelota caiga en la red.
* **Errores frecuentes:** Golpear plano o con angulo neutro ($0^\circ$), provocando que el efecto descendente de la bola contraria la haga morir en la red de inmediato.

#### Signatura Inercial (IMU)
* Vector de aceleracion previo reflejando cara abierta al techo.
* Movimiento lineal corto y uniforme hacia la red.
* Choque elastico limpio con baja dispersion en aceleracion angular post-impacto.

#### Reglas Deterministicas de Evaluacion
* **Rango ideal de angulo ($\theta_{\text{impacto}}$):** $[+25^\circ, +45^\circ]$

```{text}
SI θ_impacto < +15°:
RETORNAR "Inclina la paleta hacia atras; si entras plano el backspin rival mandara la bola a la red."
SINO SI θ_impacto > +55°:
RETORNAR "Cara excesivamente abierta; la pelota flotara alta sobre la mesa."
SINO SI Δt_pico < -40 ms:
RETORNAR "Empuja de forma fluida hacia la red; el movimiento se detuvo antes del contacto."
SINO:
RETORNAR "Empuje de reves solido: buena contencion y angulo adecuado."
```

---

## 3. Matriz Resumen de Parametros

| Golpe | Codigo ML | Angulo Optimo ($\theta$) | Condicion Critica de Falla | Consejo Prioritario |
| :--- | :---: | :---: | :--- | :--- |
| **Topspin Derecha** | `TD` | $-40^\circ \text{ a } -20^\circ$ | $\theta > -10^\circ$ (Impacto plano) | *"Cerra la cara de la paleta; el golpe fue muy plano."* |
| **Topspin Reves** | `TR` | $-35^\circ \text{ a } -15^\circ$ | $\Delta t_{\text{pico}} < -35\text{ ms}$ (Freno previo) | *"No cortes el movimiento; pasa la linea del codo."* |
| **Empuje Derecha** | `ED` | $+30^\circ \text{ a } +50^\circ$ | $\theta < +20^\circ$ o desvio lateral | *"Abri la cara y empuja recto hacia la red."* |
| **Empuje Reves** | `ER` | $+25^\circ \text{ a } +45^\circ$ | $\theta < +15^\circ$ (Entrada recta) | *"Inclina la paleta hacia atras para raspar por abajo."* |

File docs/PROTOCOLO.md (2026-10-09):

# Protocolo de Captura de Datos

Este documento define el estandar de recoleccion de datos para el entrenamiento del modelo de reconocimiento de golpes de ping pong.

## 1. Herramientas y Nomenclatura
Las capturas deben realizarse utilizando el script `herramientas/grabar.py`, que se encarga automaticamente de recolectar los datos por el puerto serie y guardarlos.

Los archivos generados se guardaran en la carpeta `datos/crudos/` siguiendo esta nomenclatura automatica:
`[YYYY-MM-DD_HHMMSS]_[jugador]_[golpe].csv`

**Ejemplo:** `2026-10-04_153000_tomas_topspin_derecha.csv`

Para visualizar los datos y verificar la integridad de la señal, utilizar el script interactivo `herramientas/ver.py`.

## 2. Protocolo de Captura en Mesa
Para garantizar que el modelo aprenda aislando el gesto tecnico puro (y no ruido de la mesa o peloteos impredecibles), se deben seguir estas reglas durante la captura:

- **No se realiza peloteo abierto.** Toda pelota debe venir de un lanzamiento (multiball).
- El alimentador lanzara **series de 10 a 20 pelotas** con un ritmo y velocidad constante.
- El jugador debe realizar el golpe y retornar brevemente a una **posicion neutra** entre cada pelota.
- El script `grabar.py` reportara los impactos procesados en tiempo real. 

## 3. Orden de los Golpes
Al utilizar `--golpe` en `grabar.py`, los nombres validos son los que define el sistema en `senal.py`. El orden de grabacion en la mesa debe ser siempre el siguiente para optimizar tiempos:

1. `topspin_derecha`
2. `empuje_derecha`
3. `topspin_reves`
4. `empuje_reves`

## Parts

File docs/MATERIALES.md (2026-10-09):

# Lista de materiales

Como solo trabajamos los viernes, **lo que no llega a tiempo nos hace perder una semana entera**. Por eso conviene comprar hoy todo lo urgente y tambien los repuestos baratos.

## Como comprar en Mercado Libre

- Filtrar por **envio Full** o "llega mañana": suele llegar en 1–2 dias. Los envios normales pueden tardar una semana.
- Juntar todo lo posible en **un mismo vendedor** para pagar un solo envio.
- Mandarlo a una direccion donde haya alguien durante la semana.
- **Revisar si el MPU6050 viene con los pines soldados.** Si vienen sueltos, hay que soldarlos.

## 1. Urgente: tiene que llegar antes del viernes 9/10

| ✓ | Material | Cant. | Buscar en ML | Para que / ojo con |
| --- | --- | --- | --- | --- |
| [ ] | Modulo MPU6050 | 2 | `MPU6050 GY-521` | Uno de repuesto. Preferir con pines soldados |
| [ ] | Cables dupont hembra-hembra, 20 cm | 1 pack de 40 | `cables dupont hembra hembra 20cm` | Conectar el sensor a la placa |
| [ ] | Cables dupont macho-hembra, 20 cm | 1 pack de 40 | `cables dupont macho hembra 20cm` | Por si hace falta usar protoboard |
| [ ] | **Cable USB de datos largo, 2–3 m** | 1 | `cable usb c datos 3 metros` | Para grabar mientras se juega: la placa manda los datos a la compu por este cable. **Tiene que ser de datos, no solo de carga**, y con la ficha que tenga su placa |
| [ ] | Precintos chicos | 1 pack | `precintos 100mm` | Atar el sensor a la paleta en las primeras pruebas |
| [ ] | Cinta de tela o aisladora | 1 | `cinta de tela` | Fijar cables al mango |
| [ ] | Pelotas de ping pong 40+ | 50 | `pelotas ping pong 40+ x 50` | Para grabar tirando de a muchas seguidas. Sirven las de entrenamiento |
| [ ] | Paleta de ping pong economica | 1 o 2 | `paleta ping pong` | Una para ponerle el sensor (se va a pegar y atar cosas). Si ya tienen, no hace falta |
| [ ] | Red retractil | 1 | `red ping pong retractil` | **Solo si la mesa de la facu no tiene red** |

## 2. Repuestos y plan B: baratos, conviene comprarlos ya

| ✓ | Material | Cant. | Buscar en ML | Para que |
| --- | --- | --- | --- | --- |
| [ ] | Disco piezoelectrico 27 mm | 3 | `piezo electrico 27mm` | Plan B si la deteccion de impactos con el acelerometro falla |
| [ ] | Resistencias de 1 MΩ | 5 | `resistencia 1M 1/4w` | Van con el piezo |

## 3. Para la capsula y la paleta sin cables (antes del 30/10)

| ✓ | Material | Cant. | Buscar en ML | Para que / ojo con |
| --- | --- | --- | --- | --- |
| [ ] | Powerbank chico | 1 | — | Alimentar la placa en el MVP. Seguro alguno tiene. **Ojo:** muchos se apagan solos cuando el consumo es bajo. Probarlo antes con la placa encendida 10 minutos |
| [ ] | Cable USB corto, 30–50 cm | 1 | `cable usb c corto 30cm` | Del powerbank a la placa |
| [ ] | Abrojo (velcro) con adhesivo | 1 m | `abrojo adhesivo` | Sujetar el cable al brazo o armar una pulsera |
| [ ] | Goma EVA | 1 plancha | `goma eva` | Amortiguar la placa dentro de la capsula |
| [ ] | Tornillos M2 × 8 mm | 1 bolsita | `tornillos m2 x 8` | Cerrar la capsula |
| [ ] | Impresion 3D de la capsula | — | Servicio de impresion o impresora de alguien | Pedir **PETG**: aguanta mejor los golpes que el PLA |

### Opcional: bateria en la paleta en vez de powerbank

Solo si quieren la paleta sin ningun cable. Agrega peso y armado.

| ✓ | Material | Cant. | Buscar en ML | Ojo con |
| --- | --- | --- | --- | --- |
| [ ] | Bateria LiPo 3,7 V, 500 mAh, con conector JST | 1 | `bateria lipo 3.7v 500mah` | — |
| [ ] | Cargador TP4056 con proteccion, USB-C | 1 | `tp4056 usb c proteccion` | Que diga "con proteccion" (tiene 6 pines de conexion, no 4) |
| [ ] | Elevador de tension MT3608 | 1 | `mt3608 step up` | La placa necesita 5 V en el pin de 5V y la bateria da 3,7 V. **Hay que regular la salida a 5 V con un multimetro antes de conectar la placa** |
| [ ] | Interruptor deslizante chico | 2 | `switch deslizante mini` | Encender y apagar |

## 4. Fase 2: video final

| ✓ | Material | Cant. | Buscar en ML | Para que |
| --- | --- | --- | --- | --- |
| [ ] | Tripode para celular | 1 | `tripode celular` | Filmar el video final de costado, a la altura de la cadera. Si alguien tiene, no hace falta |

## Herramientas (probablemente esten en el laboratorio de la facu)

Soldador y estaño, multimetro, pinza de corte, termocontraible. Si los pines del MPU6050 vienen sueltos, el soldador hace falta **el viernes 9/10**.

## Ya tenemos

- Placas ESP32-S3 N16R8 (sin usar la camara)
- Celular
- Compu
- Mesa de ping pong (a confirmar)

## Mas adelante, solo si hace falta

- **Sensor con mas rango de giro** (por ejemplo LSM6DSV16X, hasta 4000 °/s), si el MPU6050 se satura en los topspins rapidos. Puede ser dificil de conseguir en Argentina: lo vemos en la clase 1 con los primeros datos.
- **Seeed XIAO ESP32-S3**, si la placa en el mango molesta demasiado para jugar.

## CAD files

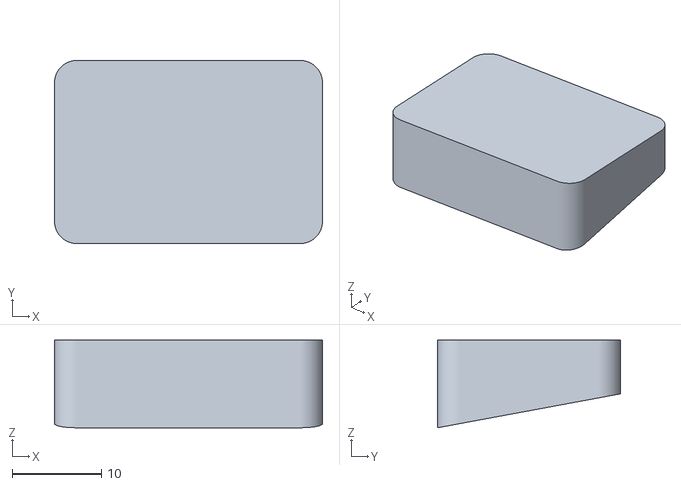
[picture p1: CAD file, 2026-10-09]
hardware/capsula_sensor_cuna.stl
30.0 x 20.5 x 9.80

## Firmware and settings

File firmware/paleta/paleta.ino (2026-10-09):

// Paleta de ping pong inteligente — firmware de la clase 1
//
// Lee el MPU-6500 por SPI 1000 veces por segundo y manda cada muestra por el puerto serie:
//   t_us,ax_g,ay_g,az_g,gx_dps,gy_dps,gz_dps,impacto
// Formato, unidades y ejes: docs/CONTRATOS.md
//
// Placa: ESP32S3 Dev Module. Configuración completa del Arduino IDE en el README.
// La cámara no se usa: se puede desconectar.

#include <SPI.h>
#include "ml_inference.h"

// Pines SPI del MPU-6500 (pin del módulo → función). Revisar en el pinout de la placa que estén libres.
// SCL y SDA quedan en los GPIO que usaba el I2C: si hay que volver a I2C, esos dos cables no se mueven.
const int PIN_SCK = 42;   // SCL → reloj
const int PIN_MOSI = 41;  // SDA → datos de la placa al sensor
const int PIN_MISO = 14;  // AD0 → datos del sensor a la placa
const int PIN_CS = 21;    // NCS → chip select
const int PIN_INT = 1;    // INT → avisa que hay una muestra nueva

// true: se lee cada vez que el sensor avisa por INT que tiene una muestra nueva. Va al ritmo del
// reloj del sensor, así no se repiten ni se saltean muestras (idea tomada del PR #5 de Mateo).
// false: plan B, se lee cada 1000 µs con micros() y el cable INT no hace falta.
const bool USAR_INT = true;

// El MPU-6500 acepta hasta 1 MHz para escribir registros y hasta 20 MHz para leer datos.
// Con cables dupont largos conviene quedarse en 1 MHz: leer una muestra tarda ~120 µs.
const SPISettings AJUSTES_SPI(1000000, MSBFIRST, SPI_MODE3);

const uint32_t PERIODO_US = 1000;  // 1000 Hz

// Escalas para ±16 g y ±2000 °/s
const float LSB_POR_G = 2048.0f;
const float LSB_POR_DPS = 16.4f;

// Offset del acelerómetro de ESTE módulo, en g y en los ejes del módulo: se resta a cada lectura.
// El eje Z de este chip lee ≈ +0,46 g de más (la hoja de datos admite hasta ±0,08 g).
// Medido el 9/10 con herramientas/calibrar.py. Si se cambia el módulo, hay que volver a medirlo.
const float OFFSET_AX_G = 0.033f;
const float OFFSET_AY_G = -0.012f;
const float OFFSET_AZ_G = 0.460f;

// Detección de impacto: salto brusco de aceleración entre dos muestras seguidas.
// El swing cambia la aceleración de a poco; el golpe con la pelota, de golpe.
// Es un primer valor: ajustarlo con herramientas/ver.py sobre golpes reales.
const float UMBRAL_SALTO_G = 1.5f;
const uint32_t REFRACTARIO_US = 300000;  // después de un impacto, ignorar 300 ms

uint32_t proximaMuestra = 0;
uint32_t ultimaLectura = 0;   // micros() de la última muestra leída
uint32_t ultimoMensaje = 0;   // para no mandar avisos por serie más de una vez por segundo
uint32_t ultimoImpacto = 0;
float axAnterior = 0, ayAnterior = 0, azAnterior = 0;
bool hayAnterior = false;

volatile uint32_t avisos = 0;  // pulsos de INT desde que arrancó: los cuenta la interrupción
uint32_t avisosLeidos = 0;     // hasta qué aviso ya se leyó
uint32_t perdidas = 0;         // muestras que el sensor tuvo listas y no se llegaron a leer

// La interrupción solo cuenta el aviso. El SPI se lee en loop(), nunca acá adentro.
void IRAM_ATTR alAvisarElSensor() {
  avisos++;
}

void escribirRegistro(uint8_t registro, uint8_t valor) {
  SPI.beginTransaction(AJUSTES_SPI);
  digitalWrite(PIN_CS, LOW);
  SPI.transfer(registro & 0x7F);  // bit 7 en 0: escritura
  SPI.transfer(valor);
  digitalWrite(PIN_CS, HIGH);
  SPI.endTransaction();
}

uint8_t leerRegistro(uint8_t registro) {
  SPI.beginTransaction(AJUSTES_SPI);
  digitalWrite(PIN_CS, LOW);
  SPI.transfer(registro | 0x80);  // bit 7 en 1: lectura
  uint8_t valor = SPI.transfer(0x00);
  digitalWrite(PIN_CS, HIGH);
  SPI.endTransaction();
  return valor;
}

// Devuelve en `id` el WHO_AM_I leído, para diagnosticar el cableado si algo falla
bool iniciarMPU(uint8_t &id) {
  escribirRegistro(0x6B, 0x80);  // PWR_MGMT_1: reset completo
  delay(100);
  escribirRegistro(0x68, 0x07);  // SIGNAL_PATH_RESET: reset de giro, acelerómetro y temperatura (recomendado en SPI)
  delay(100);
  escribirRegistro(0x6B, 0x01);  // PWR_MGMT_1: despertar, reloj del giroscopio
  delay(50);
  escribirRegistro(0x6A, 0x10);  // USER_CTRL: apagar la interfaz I2C, solo SPI

  // 0x70 = MPU-6500. 0x71 y 0x73 = MPU-9250 / MPU-9255 (el mismo sensor con magnetómetro): también sirven.
  // 0x00 o 0xFF = el sensor no contesta: revisar MISO (AD0), CS (NCS) y la alimentación.
  id = leerRegistro(0x75);  // WHO_AM_I
  if (id != 0x70 && id != 0x71 && id != 0x73) return false;

  escribirRegistro(0x1A, 0x01);  // CONFIG: filtro del giro de 184 Hz, muestreo interno a 1 kHz
  escribirRegistro(0x19, 0x00);  // SMPLRT_DIV: 1 kHz / (1 + 0)
  escribirRegistro(0x1B, 0x18);  // GYRO_CONFIG: ±2000 °/s
  escribirRegistro(0x1C, 0x18);  // ACCEL_CONFIG: ±16 g
  escribirRegistro(0x1D, 0x00);  // ACCEL_CONFIG2: filtro del acelerómetro de 218 Hz (registro nuevo del 6500)
  escribirRegistro(0x6C, 0x00);  // PWR_MGMT_2: los 6 ejes encendidos
  escribirRegistro(0x37, 0x00);  // INT_PIN_CFG: INT activo en alto, pulso de 50 µs
  escribirRegistro(0x38, 0x01);  // INT_ENABLE: avisar por INT con cada muestra nueva
  return true;
}

// Lee aceleración, temperatura y giro en una sola lectura de 14 bytes
void leerMPU(int16_t crudo[7]) {
  SPI.beginTransaction(AJUSTES_SPI);
  digitalWrite(PIN_CS, LOW);
  SPI.transfer(0x3B | 0x80);  // ACCEL_XOUT_H, lectura
  for (int i = 0; i < 7; i++) {
    uint8_t alto = SPI.transfer(0x00);
    uint8_t bajo = SPI.transfer(0x00);
    crudo[i] = (int16_t)((alto << 8) | bajo);
  }
  digitalWrite(PIN_CS, HIGH);
  SPI.endTransaction();
}

// Pasa de los ejes del módulo a los ejes de la paleta (docs/CONTRATOS.md).
// Si el módulo quedó montado girado, intercambiar o cambiar de signo acá.
void alinearEjes(float &x, float &y, float &z) {
  float mx = x, my = y, mz = z;
  x = mx;
  y = my;
  z = mz;
}

// Corre el modelo una vez al arrancar, para ver que está cargado y cuánto tarda.
// La ventana es la paleta quieta (az = 1 g): con el modelo dummy no importa qué etiqueta dé.
void probarModelo() {
  static float ventana[ML_BUFFER_LONGITUD_ESPERADA];  // static: son 4,7 kB, mejor fuera de la pila
  for (int i = 0; i < ML_BUFFER_LONGITUD_ESPERADA; i++) ventana[i] = (i % 6 == 2) ? 1.0f : 0.0f;
  ml_inicializar();
  uint32_t inicio = micros();
  PrediccionGolpe p = predecir_golpe(ventana, ML_BUFFER_LONGITUD_ESPERADA);
  float ms = (micros() - inicio) / 1000.0f;
  Serial.printf("# Modelo: %s con %.0f %% de certeza, en %.2f ms\n", p.etiqueta, p.probabilidad * 100, ms);
}

void setup() {
  Serial.begin(921600);
  delay(1500);  // tiempo para abrir el monitor serie
  pinMode(PIN_CS, OUTPUT);
  digitalWrite(PIN_CS, HIGH);  // CS en alto antes de arrancar el bus: el sensor no escucha
  SPI.begin(PIN_SCK, PIN_MISO, PIN_MOSI, PIN_CS);
  uint8_t id = 0;
  while (!iniciarMPU(id)) {
    Serial.printf("# No encuentro el MPU-6500 (WHO_AM_I = 0x%02X): revisar cables, CS y pines SPI\n", id);
    delay(1000);
  }
  Serial.printf("# MPU-6500 encontrado (WHO_AM_I = 0x%02X)\n", id);
  if (USAR_INT) {
    pinMode(PIN_INT, INPUT);
    attachInterrupt(digitalPinToInterrupt(PIN_INT), alAvisarElSensor, RISING);
    Serial.printf("# Muestreo por INT (GPIO %d)\n", PIN_INT);
  } else {
    Serial.println("# Muestreo cada 1 ms con micros() (USAR_INT = false)");
  }
  probarModelo();
  Serial.println("# Paleta lista. Columnas: t_us,ax_g,ay_g,az_g,gx_dps,gy_dps,gz_dps,impacto");
  avisosLeidos = avisos;  // los avisos que llegaron mientras se imprimía no cuentan como perdidos
  proximaMuestra = ultimaLectura = micros();
}

// Decide si toca leer una muestra: con INT, cuando el sensor avisó; en el plan B, cada 1 ms.
bool tocaLeer() {
  uint32_t ahora = micros();
  if (USAR_INT) {
    uint32_t hasta = avisos;  // copia: la interrupción lo puede cambiar en cualquier momento
    if (hasta == avisosLeidos) {
      // si el sensor no avisa nunca, el cable INT está suelto o en otro pin
      if (ahora - ultimaLectura > 1000000 && ahora - ultimoMensaje > 1000000) {
        Serial.printf("# No llega el aviso por INT (GPIO %d): revisar el cable o poner USAR_INT = false\n", PIN_INT);
        ultimoMensaje = ahora;
      }
      return false;
    }
    perdidas += hasta - avisosLeidos - 1;  // si avisó más de una vez desde la última lectura, esas muestras se perdieron
    avisosLeidos = hasta;
    return true;
  }
  if ((int32_t)(ahora - proximaMuestra) < 0) return false;
  proximaMuestra += PERIODO_US;
  if ((int32_t)(ahora - proximaMuestra) > 0) proximaMuestra = ahora + PERIODO_US;  // atrasados: retomar desde ahora
  return true;
}

void loop() {
  if (!tocaLeer()) return;
  uint32_t ahora = micros();
  ultimaLectura = ahora;

  // Las líneas con # las muestra grabar.py pero no las guarda en el CSV
  if (perdidas > 0 && ahora - ultimoMensaje > 1000000) {
    Serial.printf("# Se perdieron %lu muestras\n", (unsigned long)perdidas);
    perdidas = 0;
    ultimoMensaje = ahora;
  }

  int16_t crudo[7];
  leerMPU(crudo);

  float ax = crudo[0] / LSB_POR_G - OFFSET_AX_G;
  float ay = crudo[1] / LSB_POR_G - OFFSET_AY_G;
  float az = crudo[2] / LSB_POR_G - OFFSET_AZ_G;
  float gx = crudo[4] / LSB_POR_DPS, gy = crudo[5] / LSB_POR_DPS, gz = crudo[6] / LSB_POR_DPS;  // crudo[3] es la temperatura
  alinearEjes(ax, ay, az);
  alinearEjes(gx, gy, gz);

  int impacto = 0;
  if (hayAnterior) {
    float dx = ax - axAnterior, dy = ay - ayAnterior, dz = az - azAnterior;
    float salto = sqrtf(dx * dx + dy * dy + dz * dz);
    if (salto > UMBRAL_SALTO_G && ahora - ultimoImpacto > REFRACTARIO_US) {
      impacto = 1;
      ultimoImpacto = ahora;
    }
  }
  axAnterior = ax;
  ayAnterior = ay;
  azAnterior = az;
  hayAnterior = true;

  Serial.printf("%lu,%.3f,%.3f,%.3f,%.1f,%.1f,%.1f,%d\n",
                (unsigned long)ahora, ax, ay, az, gx, gy, gz, impacto);
}

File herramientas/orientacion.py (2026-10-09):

"""Calcula el ángulo de la cara de la paleta en cada impacto (el campo ang_deg).

Uso:
    python orientacion.py ../datos/crudos/ARCHIVO.csv
    python orientacion.py ../datos/crudos/ARCHIVO.csv --png angulo.png
    python orientacion.py ../datos/crudos/ARCHIVO.csv --quieta     # prueba con la paleta quieta
    python orientacion.py ../datos/crudos/ARCHIVO.csv --cara roja  # forzar la cara que golpea
    python orientacion.py ../datos/crudos/ARCHIVO.csv --verificar  # swings que arrancan y terminan quietos

Cómo funciona (docs/PLAN.md, sección 4.7):
1. Un filtro Madgwick sigue la orientación de la paleta en toda la sesión: integra
   el giroscopio y usa el acelerómetro (la gravedad) para corregir la deriva de a poco.
2. En el swing el acelerómetro mide mucho más que la gravedad, así que en cada impacto
   se toma la orientación de CONGELAR_S antes y desde ahí se integra solo el giroscopio.
3. El ángulo es cuánto apunta hacia arriba la normal de la cara que golpea:
   ang = asin(componente vertical de la normal). La cara roja es +Z y la negra −Z.

Convención de signo (docs/CONTRATOS.md): 0° = cara vertical, negativo = cerrada
(mira a la mesa), positivo = abierta (mira al techo). Paleta acostada con la roja
para arriba: +90° para la roja.
"""
import argparse
import math

import matplotlib
import numpy as np

from senal import FS, cargar_sesion, detectar_impactos

BETA = 0.1          # ganancia del Madgwick (la misma que trae MadgwickAHRS de Arduino)
CONGELAR_S = 0.15   # cuánto antes del impacto se deja de usar el acelerómetro
CARA_S = 0.02       # ventana antes del impacto para decidir qué cara golpeó

# Para --verificar (swings que arrancan y terminan con la paleta quieta)
QUIETO_GIRO_DPS = 15   # girando menos que esto, la paleta está quieta
QUIETO_ACEL_G = 0.1    # y el acelerómetro mide 1 g ± esto (solo la gravedad)
QUIETO_MIN_S = 0.3     # cuánto tiene que durar quieta para usarla de referencia
SWING_MIN_DPS = 200    # giro mínimo para que el movimiento entre dos quietos cuente como swing
SATURA_DPS = 1990      # el MPU-6500 mide hasta ±2000 °/s


def cuaternion_inicial(a):
    """Orientación inicial a partir de la gravedad que mide el acelerómetro (paleta quieta)."""
    a = a / np.linalg.norm(a)
    roll = math.atan2(a[1], a[2])
    pitch = math.asin(max(-1.0, min(1.0, -a[0])))
    cr, sr = math.cos(roll / 2), math.sin(roll / 2)
    cp, sp = math.cos(pitch / 2), math.sin(pitch / 2)
    return [cr * cp, sr * cp, cr * sp, -sr * sp]


def paso_madgwick(q, g, a, dt, beta):
    """Un paso del filtro: misma cuenta que updateIMU() de MadgwickAHRS (giro en rad/s).

    Con beta = 0 ignora el acelerómetro e integra solo el giroscopio.
    """
    q0, q1, q2, q3 = q
    gx, gy, gz = g
    d0 = 0.5 * (-q1 * gx - q2 * gy - q3 * gz)
    d1 = 0.5 * (q0 * gx + q2 * gz - q3 * gy)
    d2 = 0.5 * (q0 * gy - q1 * gz + q3 * gx)
    d3 = 0.5 * (q0 * gz + q1 * gy - q2 * gx)

    norma = math.sqrt(a[0] * a[0] + a[1] * a[1] + a[2] * a[2])
    if beta > 0 and norma > 0:
        ax, ay, az = a[0] / norma, a[1] / norma, a[2] / norma
        # gradiente del error entre la gravedad estimada y la medida
        s0 = 4 * q0 * q2 * q2 + 2 * q2 * ax + 4 * q0 * q1 * q1 - 2 * q1 * ay
        s1 = (4 * q1 * q3 * q3 - 2 * q3 * ax + 4 * q0 * q0 * q1 - 2 * q0 * ay - 4 * q1
              + 8 * q1 * q1 * q1 + 8 * q1 * q2 * q2 + 4 * q1 * az)
        s2 = (4 * q0 * q0 * q2 + 2 * q0 * ax + 4 * q2 * q3 * q3 - 2 * q3 * ay - 4 * q2
              + 8 * q2 * q1 * q1 + 8 * q2 * q2 * q2 + 4 * q2 * az)
        s3 = 4 * q1 * q1 * q3 - 2 * q1 * ax + 4 * q2 * q2 * q3 - 2 * q2 * ay
        ns = math.sqrt(s0 * s0 + s1 * s1 + s2 * s2 + s3 * s3)
        if ns > 0:
            d0 -= beta * s0 / ns
            d1 -= beta * s1 / ns
            d2 -= beta * s2 / ns
            d3 -= beta * s3 / ns

    q0, q1, q2, q3 = q0 + d0 * dt, q1 + d1 * dt, q2 + d2 * dt, q3 + d3 * dt
    nq = math.sqrt(q0 * q0 + q1 * q1 + q2 * q2 + q3 * q3)
    return [q0 / nq, q1 / nq, q2 / nq, q3 / nq]


def madgwick(acel, giro, fs=FS, beta=BETA):
    """Corre el filtro sobre toda la sesión. Devuelve un cuaternión (q0..q3) por muestra.

    q[k] es la orientación antes de procesar la muestra k.
    """
    giro_rad = np.radians(giro).tolist()
    acel_l = acel.tolist()
    dt = 1 / fs
    q = cuaternion_inicial(acel[0])
    salida = np.empty((len(acel), 4))
    for k in range(len(acel)):
        salida[k] = q
        q = paso_madgwick(q, giro_rad[k], acel_l[k], dt, beta)
    return salida


def angulo_roja(q):
    """Ángulo de la cara roja (+Z) respecto de la vertical, en grados. Acepta uno o varios cuaterniones."""
    q = np.asarray(q)
    # componente vertical de la normal Z = Z de la gravedad estimada (misma fórmula que el Madgwick)
    vertical = q[..., 0] ** 2 - q[..., 1] ** 2 - q[..., 2] ** 2 + q[..., 3] ** 2
    return np.degrees(np.arcsin(np.clip(vertical, -1, 1)))


def cara_que_golpea(giro, i, fs=FS):
    """Decide qué cara le pegó a la pelota según hacia dónde se movía la paleta.

    La punta de la paleta está sobre +X, así que su velocidad es ω × X = (0, ωz, −ωy):
    si ωy < 0 la paleta avanza hacia +Z y golpea la roja; si ωy > 0, la negra.
    """
    gy = giro[max(0, i - int(CARA_S * fs)):i, 1].mean()
    return "roja" if gy < 0 else "negra"


def integrar_giro(q, giro, fs=FS):
    """Parte de la orientación q y suma solo el giroscopio (giro en °/s), sin el acelerómetro."""
    q = list(q)
    for g in np.radians(giro).tolist():
        q = paso_madgwick(q, g, (0.0, 0.0, 0.0), 1 / fs, beta=0)
    return q


def angulo_en_impacto(q_sesion, giro, i, fs=FS, congelar_s=CONGELAR_S, cara="auto"):
    """Ángulo de la cara que golpea en el impacto i (en grados) y qué cara fue.

    Parte de la orientación del Madgwick congelar_s antes del impacto e integra
    solo el giroscopio hasta el impacto, para que el swing no falsee la vertical.
    """
    j = max(0, i - int(round(congelar_s * fs)))
    q = integrar_giro(q_sesion[j], giro[j:i], fs)
    if cara == "auto":
        cara = cara_que_golpea(giro, i, fs)
    ang = float(angulo_roja(q))
    return (ang if cara == "roja" else -ang), cara


def tramos_quietos(acel, giro, fs=FS):
    """Tramos (inicio, fin) donde la paleta está quieta: casi no gira y el acelerómetro mide solo la gravedad."""
    quieta = ((np.linalg.norm(giro, axis=1) < QUIETO_GIRO_DPS)
              & (np.abs(np.linalg.norm(acel, axis=1) - 1) < QUIETO_ACEL_G))
    cambios = np.diff(np.concatenate([[0], quieta.astype(int), [0]]))
    inicios, fines = np.flatnonzero(cambios == 1), np.flatnonzero(cambios == -1)
    return [(a, b) for a, b in zip(inicios, fines) if b - a >= QUIETO_MIN_S * fs]
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

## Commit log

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2026-10-04 Actualizar PLAN.md con MPU-6500, bus SPI, pines fijos y cálculo de velocidad tangencial
2026-10-04 Implementar pipeline de ingesta de datos y protocolo de captura
    [datos_prueba.csv]
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2026-10-04 Remover scripts duplicados y adaptar protocolo a herramientas/grabar.py
    [datos_prueba.csv]
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2026-10-04 Mantener nombres de columnas originales ax_g para compatibilidad con CSV Wizard de Edge Impulse
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2026-10-04 Reorganizar responsabilidades del MVP para descargar a P1 y definir arquitectura C++/BLE estricta
2026-10-04 Añadir especificaciones mecánicas, diseño Fusion 360 y rutinas de montaje para P2
2026-10-04 Actualizar diseño mecánico: mover ESP32-S3 al pomo de la paleta (capuchón) y ajustar ruteo de cables
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2026-10-04 Corregir tamaño de buffer a 1176 (196ms) y eliminar extern C innecesario en el wrapper C++
2026-10-04 Detallar paso a paso el enrutado plano de los cables SPI sobre el canto de la madera
2026-10-04 Actualizar contratos: integrar struct binario para BLE (14 bytes) y wrapper C++ de inferencia
2026-10-04 Mover todas las tareas físicas y de configuración de ESP32 de la Clase 0 a la Clase 1
2026-10-04 Añadir Plan B (salvavidas por polling) a la Clase 1 y Matriz de Riesgos para evitar bloqueos del equipo
2026-10-04 Añadir checklist de materiales a llevar para cada clase desde la 1 a la 6
2026-10-04 Actualizar lista de compras: reemplazar precintos por cintas según nuevo diseño mecánico
2026-10-04 Añadir instrucción explícita de montaje provisorio con cinta en la tarde de la Clase 1
2026-10-05 Añadir pelotas de ping pong a los materiales de la Clase 1
2026-10-05 Actualizar diseño mecánico (Fusion 360 y montaje) para incluir disco piezoeléctrico como Plan B contingente y criterio de Clase 2
2026-10-05 docs: agregar sección de Modo Tutorial interactivo en la Fase 2 del plan
2026-10-06 docs: agregar detalles de implementación del filtro Madgwick para el cálculo de ángulo
2026-10-06 docs: mover filtro IMU a Fase 1 (MVP) y agregar atajos de implementación
2026-10-09 docs: sacar acentos de todos los .md y arreglar codificacion de PLAN.md
    - Se reemplazan las vocales con tilde (á é í ó ú y mayusculas) por vocales sin tilde
    en README.md y docs/*.md. Se mantiene la ñ y los simbolos griegos (θ, Δ, ω, Ω).
    - docs/PLAN.md tenia 4 lineas guardadas en Latin-1 desde c93ca88, que GitHub mostraba
    con caracteres rotos (�). Ahora todo el archivo es UTF-8.
    - Se borran los "??" (emojis perdidos) delante de "Materiales a llevar".
2026-10-09 Corregir acentos rotos en PLAN.md y sacar referencias al proyecto de las gafas
    PLAN.md tenía 9 caracteres guardados en Latin-1 y GitHub mostraba todo el
    archivo con caracteres raros. Se pasan a UTF-8 y se agrega .editorconfig
    para que los editores guarden siempre en UTF-8.
2026-10-09 Unificar el signo del ángulo: negativo = paleta cerrada
    CONTRATOS.md decía lo contrario que GOLPES.md. Se adopta la convención de
    GOLPES.md (0° vertical, negativo cerrada, positivo abierta) en el contrato,
    el plan y la app, y los rangos de la app pasan a ser los de GOLPES.md.
2026-10-09 Paso 0 de la clase 1: libreria Arduino del modelo, ventana de 196 ms y pandas
    - firmware/armar_libreria_arduino.py reempaqueta el export C++ de Edge Impulse
    como libreria de Arduino (el IDE no compila el export C++ tal cual).
    - ml_inference.cpp incluye <ping_pong_classifier_inferencing.h>: con el include
    anterior paleta.ino no compilaba.
    - segmentar.py corta 120 + 76 = 196 muestras, lo que espera el modelo
    (ML_BUFFER_LONGITUD_ESPERADA = 1176 = 196 x 6).
    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
2026-10-09 Agregar cálculo del ángulo de la cara (Madgwick)
    - herramientas/orientacion.py: ángulo de la cara en cada impacto (ang_deg).
    Madgwick igual a updateIMU() de MadgwickAHRS para que el firmware dé lo
    mismo; 150 ms antes del impacto deja de usar el acelerómetro e integra
    solo el giroscopio. La cara que golpea sale del signo de gy (gy < 0 = roja).
    --quieta muestra el ángulo cada medio segundo para validar con la paleta
    quieta en ángulos conocidos.
    - herramientas/prueba_orientacion.py: sesión simulada con el ángulo real
    conocido; error máximo 0,4°.
    [orientacion.py, prueba_orientacion.py]
2026-10-09 Topspin de derecha: rango de ángulo ideal −40° a −20°
    GOLPES.md tenía dos rangos para TD (−30…−10 en la sección y −40…−20 en
    la tabla resumen). Queda −40…−20 en GOLPES.md, la app y CONTRATOS.md.
    Los umbrales del pseudocódigo de TD se corren los mismos −10° (+5 → −5,
    −35 → −45), porque −35 quedaba dentro del rango ideal.
2026-10-09 Agregar AGENTS.md con las reglas del repo y el flujo con ramas y PR
    Cada uno trabaja con su asistente (Claude, Gemini): AGENTS.md junta lo que
    todos tienen que respetar (quién toca qué carpeta, pull antes de empezar, una
    rama por tarea y PR a main, convenciones de CONTRATOS.md, qué no va a git).
    CLAUDE.md y GEMINI.md solo lo importan, así hay un solo lugar para las reglas.
    PLAN.md decía ramas largas por módulo (firmware, datos, app); pasa a una
    rama corta por tarea, que es lo que permite la protección de main.
2026-10-09 Agregar --verificar a orientacion.py: error del giroscopio en swings reales
    Con la paleta en movimiento no hay contra qué comparar el ángulo del impacto.
    --verificar busca swings que arrancan y terminan con la paleta quieta: parte
    del ángulo que mide el acelerómetro quieta, suma solo el giroscopio durante el
    swing (como en el impacto) y lo compara con lo que mide el acelerómetro cuando
    vuelve a quedar quieta. La diferencia es el error que acumula el giroscopio.
    También avisa si el giro llegó al máximo del sensor (±2000 °/s).
    prueba_orientacion.py lo chequea en la sesión simulada: error máximo 0,4°.
    [orientacion.py, prueba_orientacion.py]
2026-10-09 Agregar cinematica.py: velocidad, pico de giro y estimación de L
    - Una fila por golpe con lo que la placa le manda a la app: ángulo, velocidad
    (v = ω · L, solo con el giro que mueve la paleta hacia adelante) y pico de
    giro respecto del impacto (negativo = antes).
    - --estimar-L mide la distancia del eje de giro al sensor con la aceleración
    centrípeta (a_x = −ω² · r): resta la gravedad con el Madgwick y ajusta una
    recta con las muestras de giro fuerte que no saturan el acelerómetro.
    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
2026-10-09 Distancia del sensor al centro de la paleta: 9 cm medidos con regla
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2026-10-09 Calibrar el offset del acelerometro y agregar calibrar.py
    El eje Z de este módulo lee ≈ +0,46 g de más (la hoja de datos admite
    ±0,08 g): acostado daba |a| = 1,47 g. El offset de cada eje se resta en
    paleta.ino (OFFSET_AX_G, OFFSET_AY_G, OFFSET_AZ_G).
    herramientas/calibrar.py lo calcula a partir de una grabación con el
    módulo quieto en 6 posiciones: busca los tramos sin giro y ajusta el
    offset para que en todos la aceleración total dé 1 g. Con este módulo:
    +0,033 / −0,012 / +0,460 g, error residual ≤ 0,02 g. Después de cargarlo,
    acostado da az = 1,000 g. Si se cambia el módulo hay que recalibrar.
    [calibrar.py, paleta.ino]
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2026-10-09 Agregar STL de la capsula del sensor (Pieza 1)
    [capsula_sensor_cuna.stl]
